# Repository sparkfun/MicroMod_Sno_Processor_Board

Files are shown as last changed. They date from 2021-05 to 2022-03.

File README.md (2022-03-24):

SparkFun MicroMod Alorium Sno M2 Processor Board
========================================

MicroMod Alorium Sno Processor Board (https://www.sparkfun.com/products/18030)

[*SparkFun MicroMod Alorium Sno M2 Processor Board (18030)*](https://www.sparkfun.com/products/18030)

The [MicroMod Alorium Sno M2 Processor Board](https://www.sparkfun.com/products/18030) features the Snō System on Module (SoM) from Alorium Technology adapted to the MicroMod M.2 processor form factor. Snō's FPGA provides a reconfigurable hardware platform that hosts an 8-bit AVR instruction set, compatible with the ATmega328, making Snō fully compatible with the Arduino IDE. Snō SoM has a compact footprint, making it ideal for space-constrained applications and an obvious addition to our MicroMod form factor for prototyping. 

Alorium Technology provides a library of custom logic called Xcelerator Blocks (XBs) through the Arduino IDE that accelerate specific functionality that is slow, problematic, or even impossible for an 8-bit microcontroller. This library includes XBs such as Servo Control, Quadrature, Floating Point Math, NeoPixel, and Enhanced Analog-to-Digital Converter. Alorium also notes a XB roadmap where future XBs will be implemented based on feedback
from early adopters and new potential customers. 

Repository Contents
-------------------

* **/Hardware** - Eagle design files (.brd, .sch)

Documentation
--------------
* **[Hookup Guide](https://learn.sparkfun.com/tutorials/micromod-alorium-sno-processor-board-hookup-guide)** - Basic hookup guide for the SparkFun MicroMod Alorium Sno Processor Board.

License Information
-------------------

This product is _**open source**_! 

Please review the LICENSE.md file for license information. 

If you have any questions or concerns on licensing, please contact technical support on our [SparkFun forums](https://forum.sparkfun.com/viewforum.php?f=152).

Distributed as-is; no warranty is given.

- Your friends at SparkFun.

_<COLLABORATION CREDIT>_

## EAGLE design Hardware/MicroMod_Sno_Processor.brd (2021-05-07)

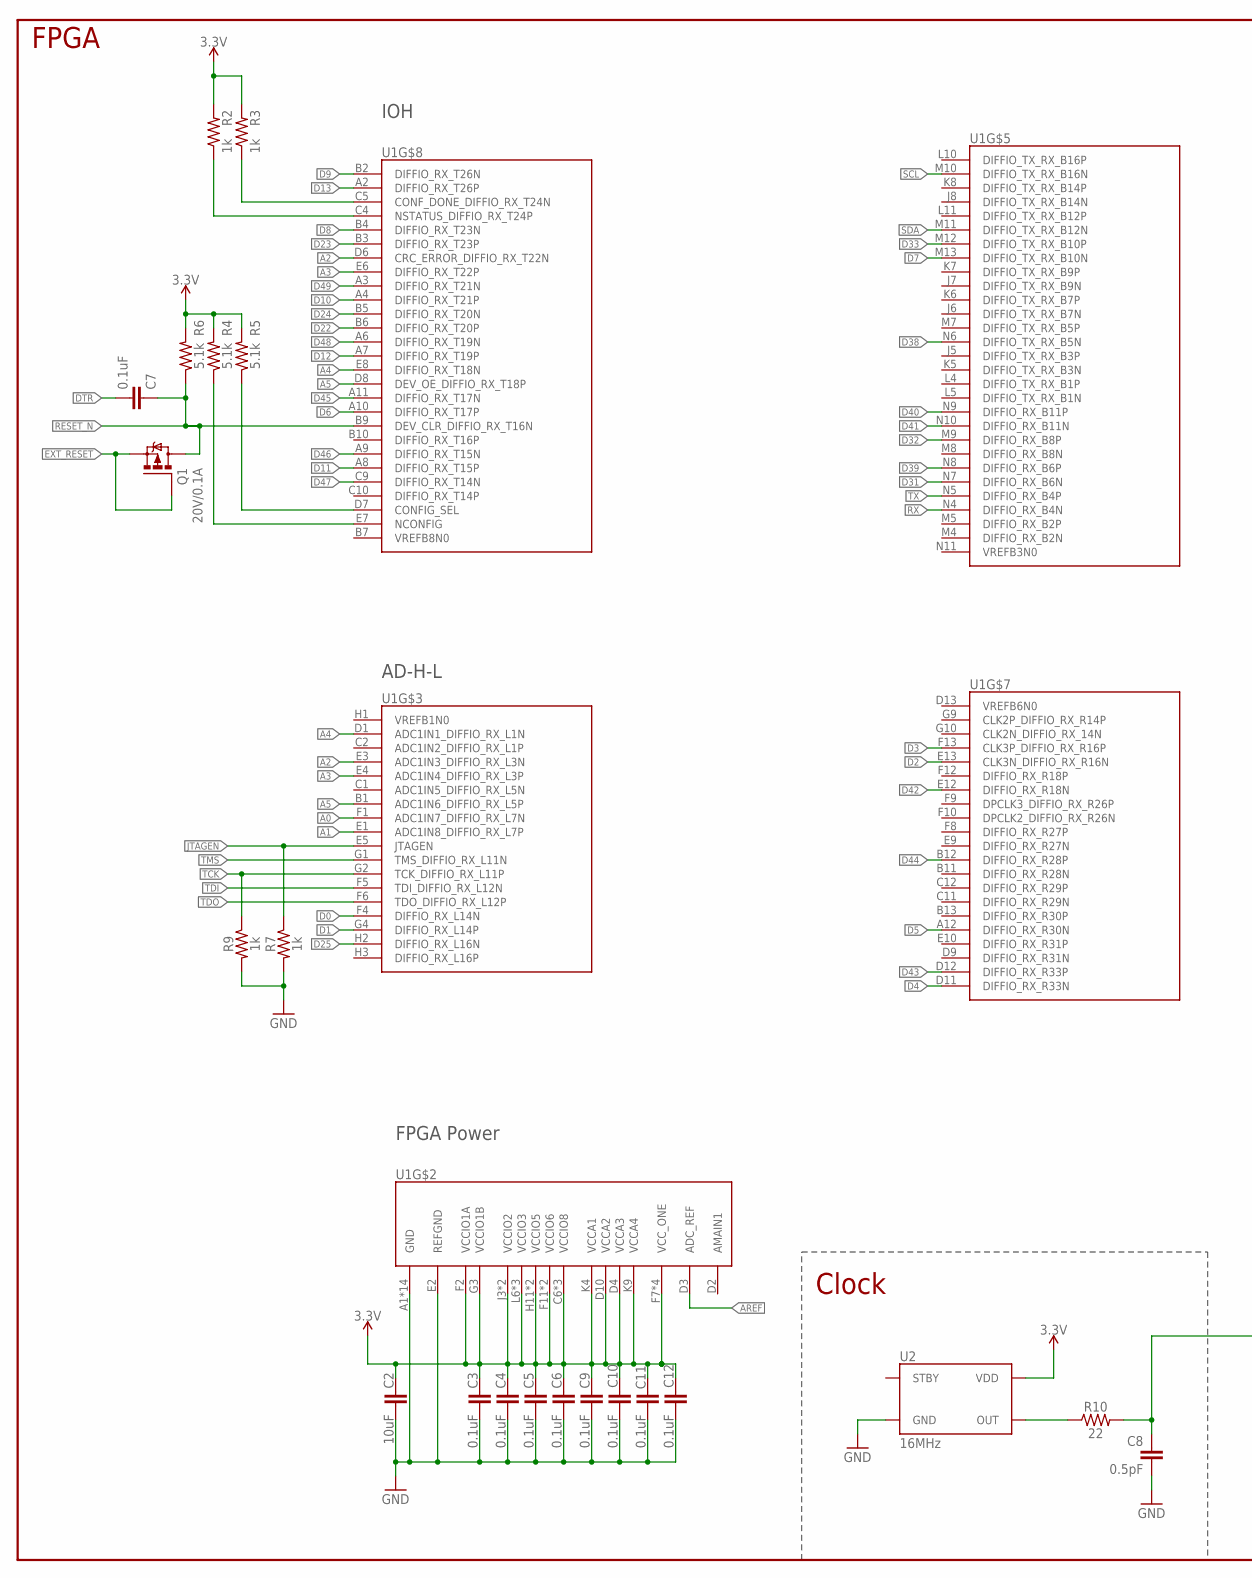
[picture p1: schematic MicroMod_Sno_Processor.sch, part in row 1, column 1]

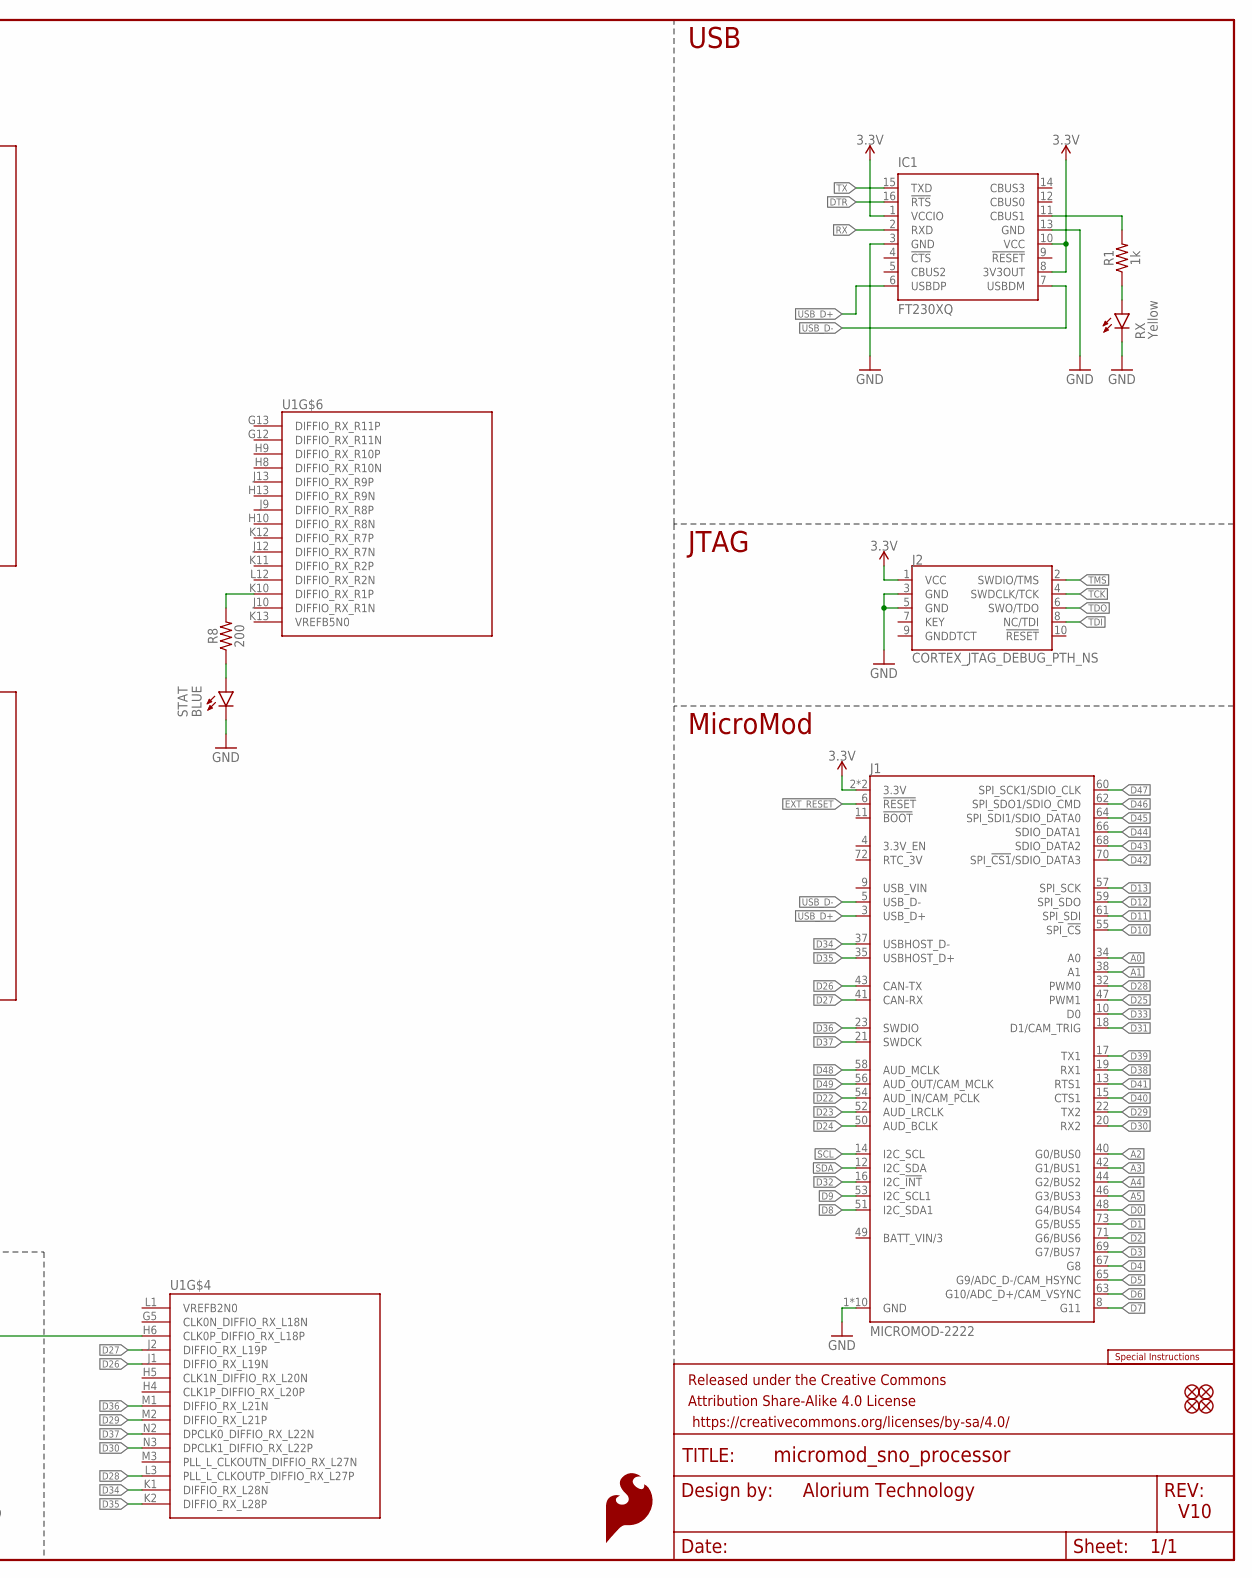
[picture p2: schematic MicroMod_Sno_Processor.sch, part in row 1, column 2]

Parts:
C2: 10uF; 0402-TIGHT
C3, C4, C5, C6, C7, C9, C10, C11, C12: 0.1uF; 0402-TIGHT
C8: 0.5pF; 0402-TIGHT
FID1, FID2, FID3, FID4: FIDUCIAL1X2; FIDUCIAL-1X2
FRAME1: FRAME-LEDGER; CREATIVE_COMMONS
IC1: FT230XQ; QFN16
J1: MICROMOD-2222; M.2-CARD-E-22
J2: CORTEX_JTAG_DEBUG_PTH_NS; 2X5-PTH-1.27MM-NO_SILK
LOGO1: SPECIAL_INSTRUCTIONS-ORDERING; ORDERING_INSTRUCTIONS
LOGO2: SFE_LOGO_FLAME.1_INCH; SFE_LOGO_FLAME_.1
Q1: 20V/0.1A; SOT-416
R1, R2, R3, R7, R9: 1k; 0402-TIGHT
R4, R5, R6: 5.1k; 0402-TIGHT
R8: 200; 0402-TIGHT
R10: 22; 0402-TIGHT
RX: Yellow; LED-0603
STAT: BLUE; LED-0603
U1: 10M08SA; UBGA_169
U2: 16MHz; SMD20X16

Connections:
3.3V: C2.1, C3.1, C4.1, C5.1, C6.1, C9.1, C10.1, C11.1, C12.1, IC1.1 (VCCIO), IC1.8 (3V3OUT), IC1.10 (VCC), J1.2 (3.3V), J1.74 (3.3V), J2.1 (VCC), R2.2, R3.2, R4.2, R5.2, R6.2, U1.C6 (VCCIO8), U1.C7 (VCCIO8), U1.C8 (VCCIO8), U1.D4 (VCCA3), U1.D10 (VCCA2), U1.F2 (VCCIO1A), U1.F7 (VCC_ONE), U1.F11 (VCCIO6), U1.G3 (VCCIO1B), U1.G6 (VCC_ONE), U1.G8 (VCC_ONE), U1.G11 (VCCIO6), U1.H7 (VCC_ONE), U1.H11 (VCCIO5), U1.J3 (VCCIO2), U1.J11 (VCCIO5), U1.K3 (VCCIO2), U1.K4 (VCCA1), U1.K9 (VCCA4), U1.L6 (VCCIO3), U1.L7 (VCCIO3), U1.L8 (VCCIO3), U2.4 (VDD)
A0: J1.34 (A0), U1.F1 (ADC1IN7_DIFFIO_RX_L7N)
A1: J1.38 (A1), U1.E1 (ADC1IN8_DIFFIO_RX_L7P)
A2: J1.40 (G0/BUS0), U1.D6 (CRC_ERROR_DIFFIO_RX_T22N), U1.E3 (ADC1IN3_DIFFIO_RX_L3N)
A3: J1.42 (G1/BUS1), U1.E4 (ADC1IN4_DIFFIO_RX_L3P), U1.E6 (DIFFIO_RX_T22P)
A4: J1.44 (G2/BUS2), U1.D1 (ADC1IN1_DIFFIO_RX_L1N), U1.E8 (DIFFIO_RX_T18N)
A5: J1.46 (G3/BUS3), U1.B1 (ADC1IN6_DIFFIO_RX_L5P), U1.D8 (DEV_OE_DIFFIO_RX_T18P)
AREF: U1.D3 (ADC_REF)
CLK: C8.1, R10.2, U1.H6 (CLK0P_DIFFIO_RX_L18P)
D0: J1.48 (G4/BUS4), U1.F4 (DIFFIO_RX_L14N)
D1: J1.73 (G5/BUS5), U1.G4 (DIFFIO_RX_L14P)
D2: J1.71 (G6/BUS6), U1.E13 (CLK3N_DIFFIO_RX_R16N)
D3: J1.69 (G7/BUS7), U1.F13 (CLK3P_DIFFIO_RX_R16P)
D4: J1.67 (G8), U1.D11 (DIFFIO_RX_R33N)
D5: J1.65 (G9/ADC_D-/CAM_HSYNC), U1.A12 (DIFFIO_RX_R30N)
D6: J1.63 (G10/ADC_D+/CAM_VSYNC), U1.A10 (DIFFIO_RX_T17P)
D7: J1.8 (G11), U1.M13 (DIFFIO_TX_RX_B10N)
D8: J1.51 (I2C_SDA1), U1.B4 (DIFFIO_RX_T23N)
D9: J1.53 (I2C_SCL1), U1.B2 (DIFFIO_RX_T26N)
D10: J1.55 (SPI_!CS!), U1.A4 (DIFFIO_RX_T21P)
D11: J1.61 (SPI_SDI), U1.A8 (DIFFIO_RX_T15P)
D12: J1.59 (SPI_SDO), U1.A7 (DIFFIO_RX_T19P)
D13: J1.57 (SPI_SCK), U1.A2 (DIFFIO_RX_T26P)
D22: J1.54 (AUD_IN/CAM_PCLK), U1.B6 (DIFFIO_RX_T20P)
D23: J1.52 (AUD_LRCLK), U1.B3 (DIFFIO_RX_T23P)
D24: J1.50 (AUD_BCLK), U1.B5 (DIFFIO_RX_T20N)
D25: J1.47 (PWM1), U1.H2 (DIFFIO_RX_L16N)
D26: J1.43 (CAN-TX), U1.J1 (DIFFIO_RX_L19N)
D27: J1.41 (CAN-RX), U1.J2 (DIFFIO_RX_L19P)
D28: J1.32 (PWM0), U1.L3 (PLL_L_CLKOUTP_DIFFIO_RX_L27P)
D29: J1.22 (TX2), U1.M2 (DIFFIO_RX_L21P)
D30: J1.20 (RX2), U1.N3 (DPCLK1_DIFFIO_RX_L22P)
D31: J1.18 (D1/CAM_TRIG), U1.N7 (DIFFIO_RX_B6N)
D32: J1.16 (I2C_!INT!), U1.M9 (DIFFIO_RX_B8P)
D33: J1.10 (D0), U1.M12 (DIFFIO_TX_RX_B10P)
D34: J1.37 (USBHOST_D-), U1.K1 (DIFFIO_RX_L28N)
D35: J1.35 (USBHOST_D+), U1.K2 (DIFFIO_RX_L28P)
D36: J1.23 (SWDIO), U1.M1 (DIFFIO_RX_L21N)
D37: J1.21 (SWDCK), U1.N2 (DPCLK0_DIFFIO_RX_L22N)
D38: J1.19 (RX1), U1.N6 (DIFFIO_TX_RX_B5N)
D39: J1.17 (TX1), U1.N8 (DIFFIO_RX_B6P)
D40: J1.15 (CTS1), U1.N9 (DIFFIO_RX_B11P)
D41: J1.13 (RTS1), U1.N10 (DIFFIO_RX_B11N)
D42: J1.70 (SPI_!CS1!/SDIO_DATA3), U1.E12 (DIFFIO_RX_R18N)
D43: J1.68 (SDIO_DATA2), U1.D12 (DIFFIO_RX_R33P)
D44: J1.66 (SDIO_DATA1), U1.B12 (DIFFIO_RX_R28P)
D45: J1.64 (SPI_SDI1/SDIO_DATA0), U1.A11 (DIFFIO_RX_T17N)
D46: J1.62 (SPI_SDO1/SDIO_CMD), U1.A9 (DIFFIO_RX_T15N)
D47: J1.60 (SPI_SCK1/SDIO_CLK), U1.C9 (DIFFIO_RX_T14N)
D48: J1.58 (AUD_MCLK), U1.A6 (DIFFIO_RX_T19N)
D49: J1.56 (AUD_OUT/CAM_MCLK), U1.A3 (DIFFIO_RX_T21N)
DTR: C7.2, IC1.16 (!RTS)
EXT_RESET: J1.6 (!RESET!), Q1.P1 (G), Q1.P2 (S)
GND: C2.2, C3.2, C4.2, C5.2, C6.2, C8.2, C9.2, C10.2, C11.2, C12.2, IC1.3 (GND), IC1.13 (GND), J1.1 (GND), J1.7 (GND), J1.33 (GND), J1.36 (GND), J1.39 (GND), J1.45 (GND), J1.75 (GND), J1.GND1 (GND), J1.GND2 (GND), J1.GND3 (GND), J2.3 (GND), J2.5 (GND), R7.2, R9.2, RX.C, STAT.C, U1.A1 (GND), U1.A13 (GND), U1.B8 (GND), U1.C3 (GND), U1.D5 (GND), U1.E2 (REFGND), U1.E11 (GND), U1.F3 (GND), U1.G7 (GND), U1.H12 (GND), U1.J4 (GND), U1.L9 (GND), U1.M6 (GND), U1.N1 (GND), U1.N13 (GND), U2.2 (GND)
JTAGEN: R7.1, U1.E5 (JTAGEN)
unnamed: R1.1, RX.A
unnamed: R3.1, U1.C5 (CONF_DONE_DIFFIO_RX_T24N)
unnamed: R8.1, STAT.A
unnamed: R2.1, U1.C4 (NSTATUS_DIFFIO_RX_T24P)
unnamed: R5.1, U1.D7 (CONFIG_SEL)
NCONFIG: R4.1, U1.E7 (NCONFIG)
OSC: R10.1, U2.3 (OUT)
RESET_N: C7.1, Q1.P3 (D), R6.1, U1.B9 (DEV_CLR_DIFFIO_RX_T16N)
RX: IC1.2 (RXD), U1.N4 (DIFFIO_RX_B4N)
RXLED: IC1.11 (CBUS1), R1.2
SCL: J1.14 (I2C_SCL), U1.M10 (DIFFIO_TX_RX_B16N)
SDA: J1.12 (I2C_SDA), U1.M11 (DIFFIO_TX_RX_B12N)
STAT: R8.2, U1.K10 (DIFFIO_RX_R1P)
TCK: J2.4 (SWDCLK/TCK), R9.1, U1.G2 (TCK_DIFFIO_RX_L11P)
TDI: J2.8 (NC/TDI), U1.F5 (TDI_DIFFIO_RX_L12N)
TDO: J2.6 (SWO/TDO), U1.F6 (TDO_DIFFIO_RX_L12P)
TMS: J2.2 (SWDIO/TMS), U1.G1 (TMS_DIFFIO_RX_L11N)
TX: IC1.15 (TXD), U1.N5 (DIFFIO_RX_B4P)
USB_D+: IC1.6 (USBDP), J1.3 (USB_D+)
USB_D-: IC1.7 (USBDM), J1.5 (USB_D-)

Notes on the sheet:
IOH
AD-H-L
FPGA Power
Clock
USB
FPGA
JTAG
MicroMod
V10
Alorium Technology

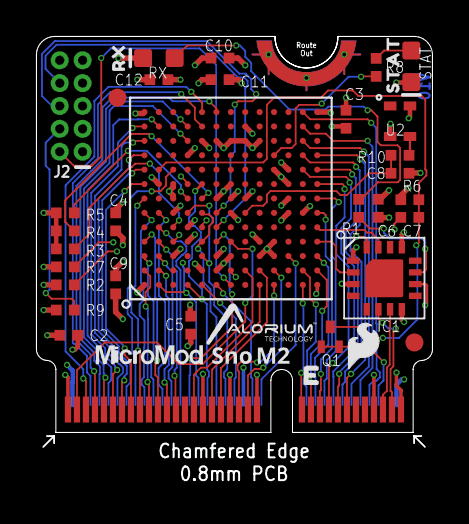
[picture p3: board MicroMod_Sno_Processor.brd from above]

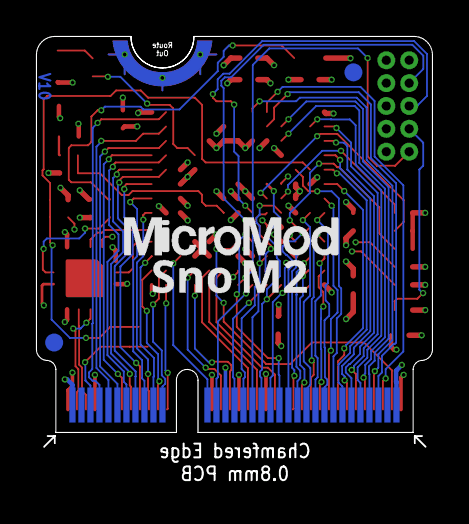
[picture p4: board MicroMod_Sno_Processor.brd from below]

Board: 4 copper layers, 22.0 x 22.8 mm, 38 parts (2 on the bottom side), 74 nets.

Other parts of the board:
U$1: STAT0
U$2: RX0

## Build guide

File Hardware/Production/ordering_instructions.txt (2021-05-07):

panel size, 194x70mm
PCB thickness, 0.8mm
number of layers, 4
soldermask color, Red
silkscreen color, White
oz copper, 1oz
finish, ENIG
stencils, top
pcs per panel, 16
min trace width, 0.1016mm / 0.0040in
min drill size, 0.2000mm / 0.0079in
filename to layer stackup 1/2/3/4: GTL, GL2, GL3, GBL

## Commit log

2021-05-04 V10 Update
    Updated routing for DFM and proto issues
    [MicroMod_Sno_Processor-Panel.GBL, MicroMod_Sno_Processor-Panel.GBO, MicroMod_Sno_Processor-Panel.GBP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]
2021-05-06 V10 QC changes
    - Added voltage range to FPGA
    - Updated RX LED to yellow
    - Updated PROD_ID for 22 ohm resistor
    [MicroMod_Sno_Processor.brd, MicroMod_Sno_Processor.sch]
2021-05-07 Updated oscillator
    Updated oscillator to a smaller 2.0x1.6mm package
    [MicroMod_Sno_Processor.brd, MicroMod_Sno_Processor.sch]
2021-05-07 Update MicroMod_Sno_Processor.sch
    Added VCC range note back to schematic
    [MicroMod_Sno_Processor.sch]
2021-05-07 Added panel gerbers
    [MicroMod_Sno_Processor-Panel.GBL, MicroMod_Sno_Processor-Panel.GBO, MicroMod_Sno_Processor-Panel.GBP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]

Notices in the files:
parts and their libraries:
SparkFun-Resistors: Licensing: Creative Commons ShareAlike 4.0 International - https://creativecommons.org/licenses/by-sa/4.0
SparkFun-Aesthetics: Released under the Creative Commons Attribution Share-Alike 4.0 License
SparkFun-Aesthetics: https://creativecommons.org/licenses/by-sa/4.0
